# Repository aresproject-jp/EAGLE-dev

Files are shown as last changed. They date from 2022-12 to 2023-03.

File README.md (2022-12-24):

# EAGLE-dev
## projects
ARES3号機向けの回路の共同開発用ワークスペースです。
EAGLEのschファイルとbrdファイルを同じ名前のフォルダ内に保存して管理して下さい。
EAGLEの推奨バージョンは9.6.2です。
## libraries
各モジュールのライブラリを共有します。/computers /sensors /element /motor /connectorの5つの
フォルダを用意しています。以下の基準に従って分類して下さい。
- computers : コンピュータ及びマイクロコンピュータ　ex)jetson nano, raspberypi, arduino
- sensors   : 各センサモジュール　ex)BNO055, BMP180
- element   : 回路素子　ex)PchMosfet, DCDCconverter
- motor     : モーター関連のモジュール　ex)モータードライバ, エンコーダ
- connector : コネクタ類
## 3Dmodels
EAGLEにデフォルトで3Dデータが登録されていない部品の3Dデータ(*step)をアップロードしてください。
分類方法はlibrariesと同様です。
## documets
参考資料およびシステム図

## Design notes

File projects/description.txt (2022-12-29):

any comment is OK

power_supply => @kato shunsuke
jetson => @saizaki tomoki
arduino => @higuchi fuka

controll unit{
    module:jetson, BNO055, BMP180, CAN(MCP2562), GPS, 2.4GHz wireless communication module
    powersupply:5V from PU
    fan
    camera
    interface:terminalblock => 5V,GND CANH,CAL * 2

    eagle library:jetson, GPS, wirelessPin(5V,3V3, GND, RX, TX) 15min * 3 = 45min
    schematic 60min
    bord 30min
    3D ×
    deadline 1/3

    progress:
}

motor unit{
    module:ArduinoMega, motordriver(screw hole + terminalblock),CAN, encoder(4lines)
    powersupply:5V,18V from PU
    interface:terminalblock => 5V,GND,18V,CANH,CANL * 2
              connector => 4*4
    eagle library:motordriver,MCP2515r,ArduinoMega
}

power unit{
    eagle library:pulse generator
}

asks{
    systems, write down questions => kato
    e-mail => zaki
    deadline 1/3
}

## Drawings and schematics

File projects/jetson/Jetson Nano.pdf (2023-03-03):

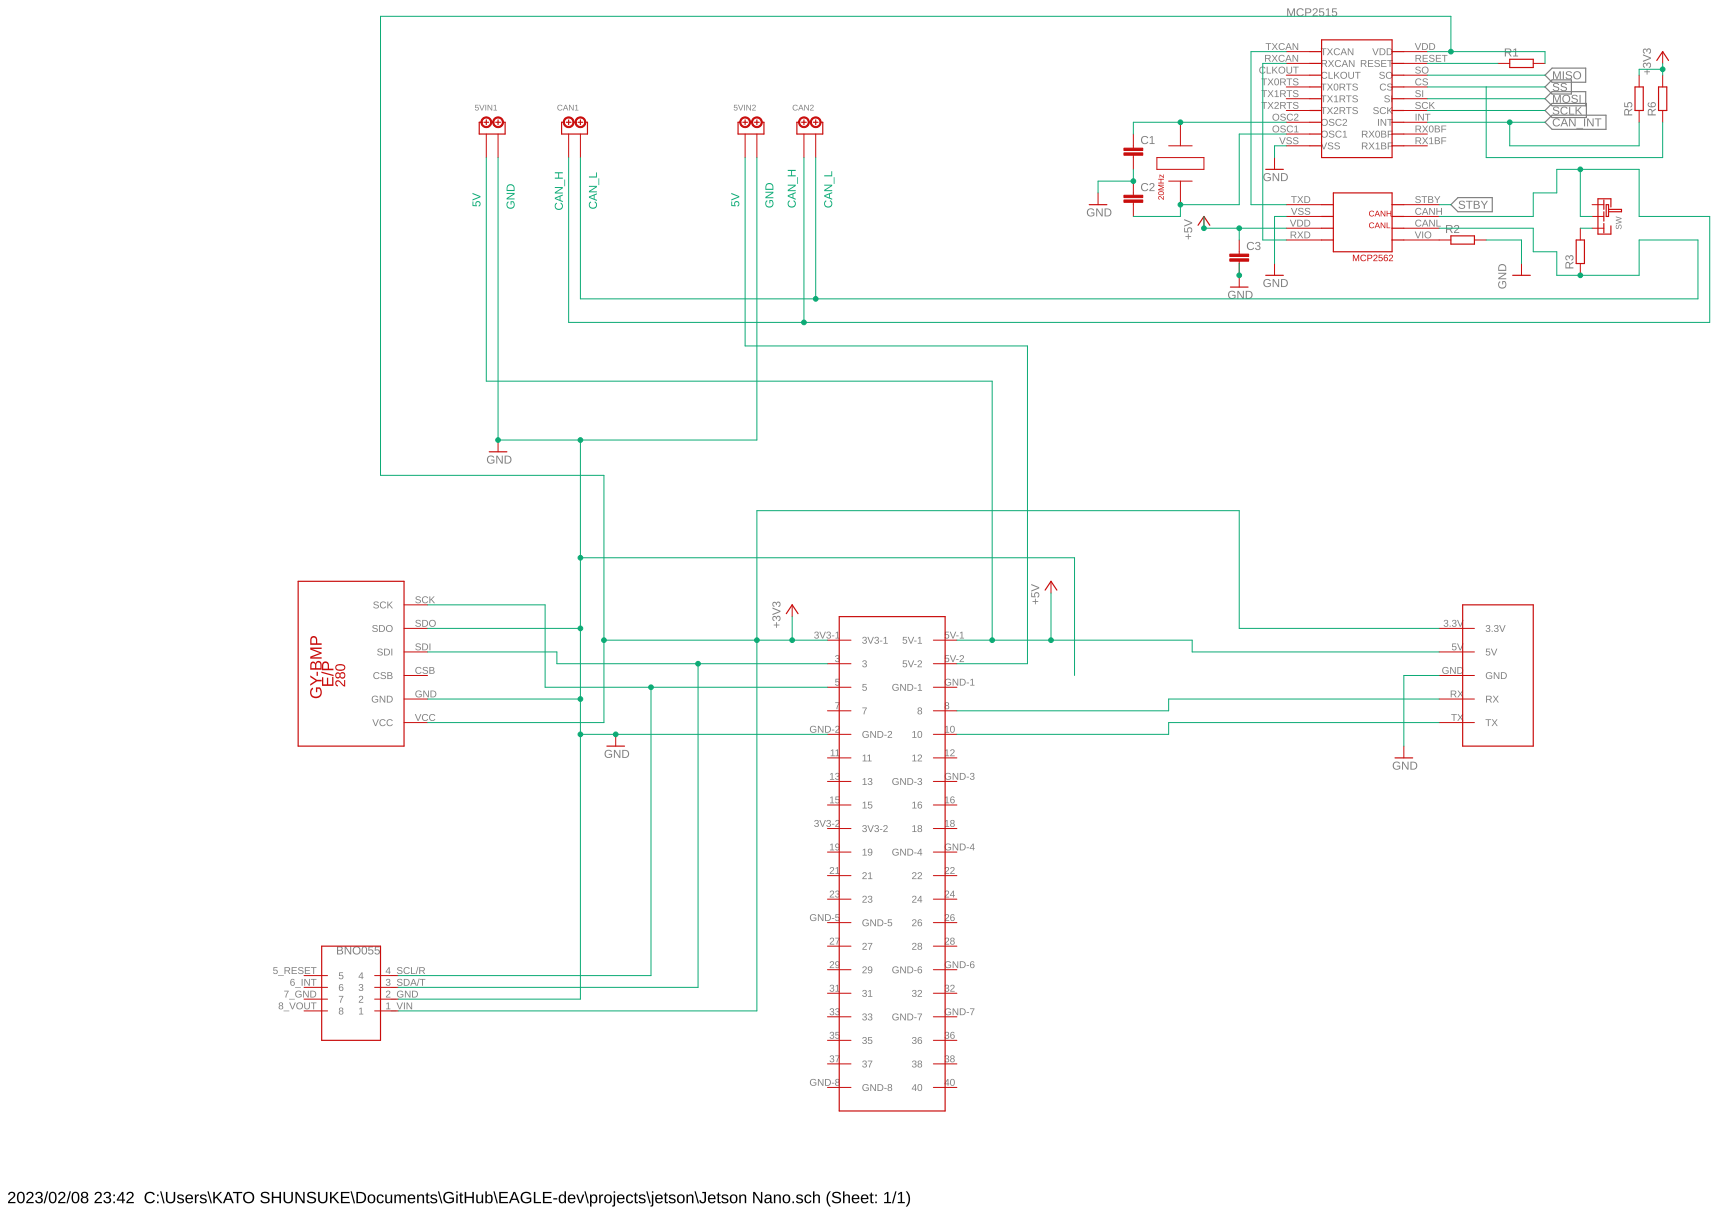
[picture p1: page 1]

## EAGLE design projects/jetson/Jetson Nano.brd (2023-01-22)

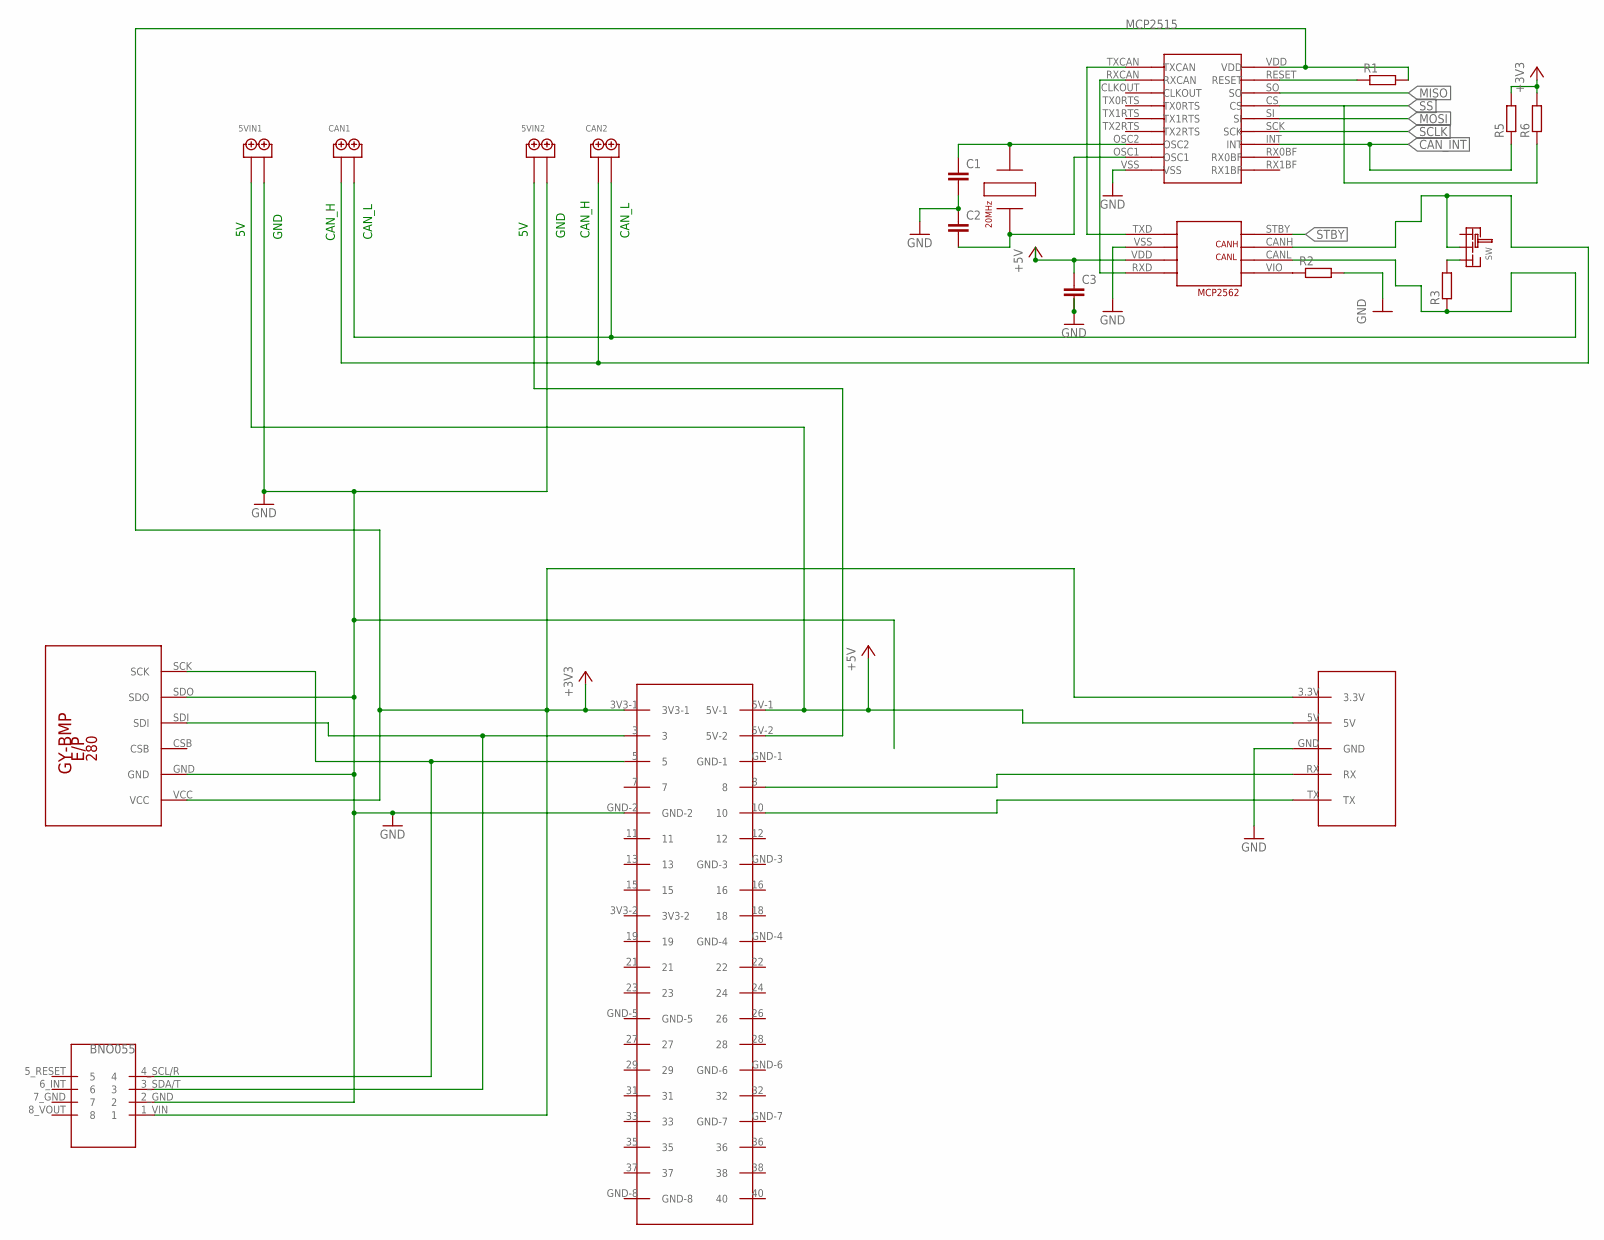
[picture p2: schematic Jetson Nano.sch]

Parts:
5VIN1, 5VIN2: 2PIN
C1, C2, C3: C-EU025-024X044; C025-024X044
CAN1, CAN2: 2PIN
JN1: JETSON_NANO
MCP1: MCP2515
R1, R2, R3, R5, R6: R-EU_0207/10; 0207/10
SW: SRIDE_SWITCH
U$1: GY-BPM280; GY-BMP280-FOOTPRINT
U$2: BNO055
U$3: WIRELESS_PINS
U$4: MCP2562
U$5: HUSG20

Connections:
5V_2: 5VIN2.P$1, JN1.5V-2
+3V3: JN1.3V3-1, MCP1.VDD, R1.2, R5.2, R6.2, U$1.VCC, U$2.1_VIN (1), U$3.3.3V
+5V_1: 5VIN1.P$1, C3.1, JN1.5V-1, U$3.5V, U$4.VDD
CAN_H2: CAN1.P$1, CAN2.P$1, SW.LR, U$4.CANH
CAN_INT: MCP1.INT, R5.1
GND: 5VIN1.P$2, 5VIN2.P$2, C1.2, C2.1, C3.2, JN1.GND-2, MCP1.VSS, U$1.GND, U$1.SDO, U$2.2_GND (2), U$3.GND, U$4.VSS
MISO: MCP1.SO
MOSI: MCP1.SI
unnamed: JN1.3, U$1.SDI, U$2.3_SDA/T (3)
unnamed: JN1.5, U$1.SCK, U$2.4_SCL/R (4)
unnamed: C1.1, MCP1.OSC2, U$5.A
unnamed: C2.2, MCP1.OSC1, U$5.B
unnamed: MCP1.TXCAN, U$4.TXD
unnamed: MCP1.RXCAN, U$4.RXD
unnamed: JN1.8, U$3.RX
unnamed: JN1.10, U$3.TX
unnamed: MCP1.RESET, R1.1
unnamed: R2.1, U$4.VIO
unnamed: R3.2, SW.R
unnamed: CAN1.P$2, CAN2.P$2, R3.1, U$4.CANL
SCLK: MCP1.SCK
SS: MCP1.CS, R6.1
STBY: U$4.STBY

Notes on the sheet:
GND
CAN_H
CAN_L

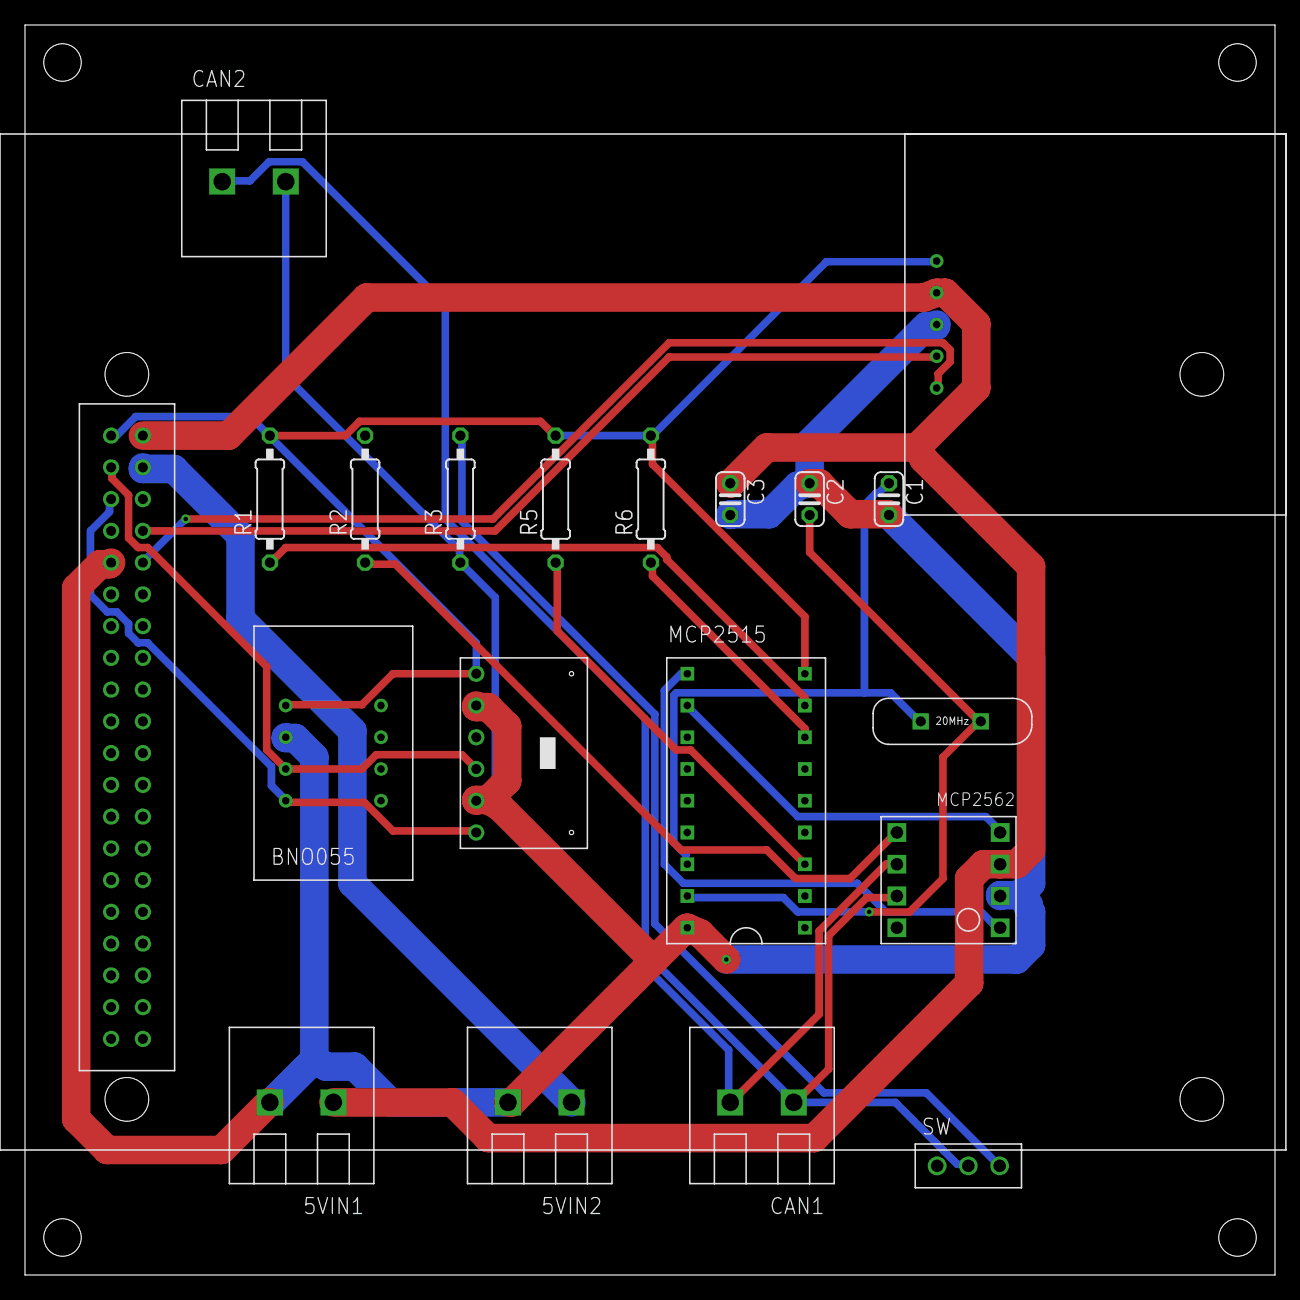
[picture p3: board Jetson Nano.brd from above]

Board: 2 copper layers, 100.0 x 100.0 mm, 20 parts (0 on the bottom side), 19 nets.

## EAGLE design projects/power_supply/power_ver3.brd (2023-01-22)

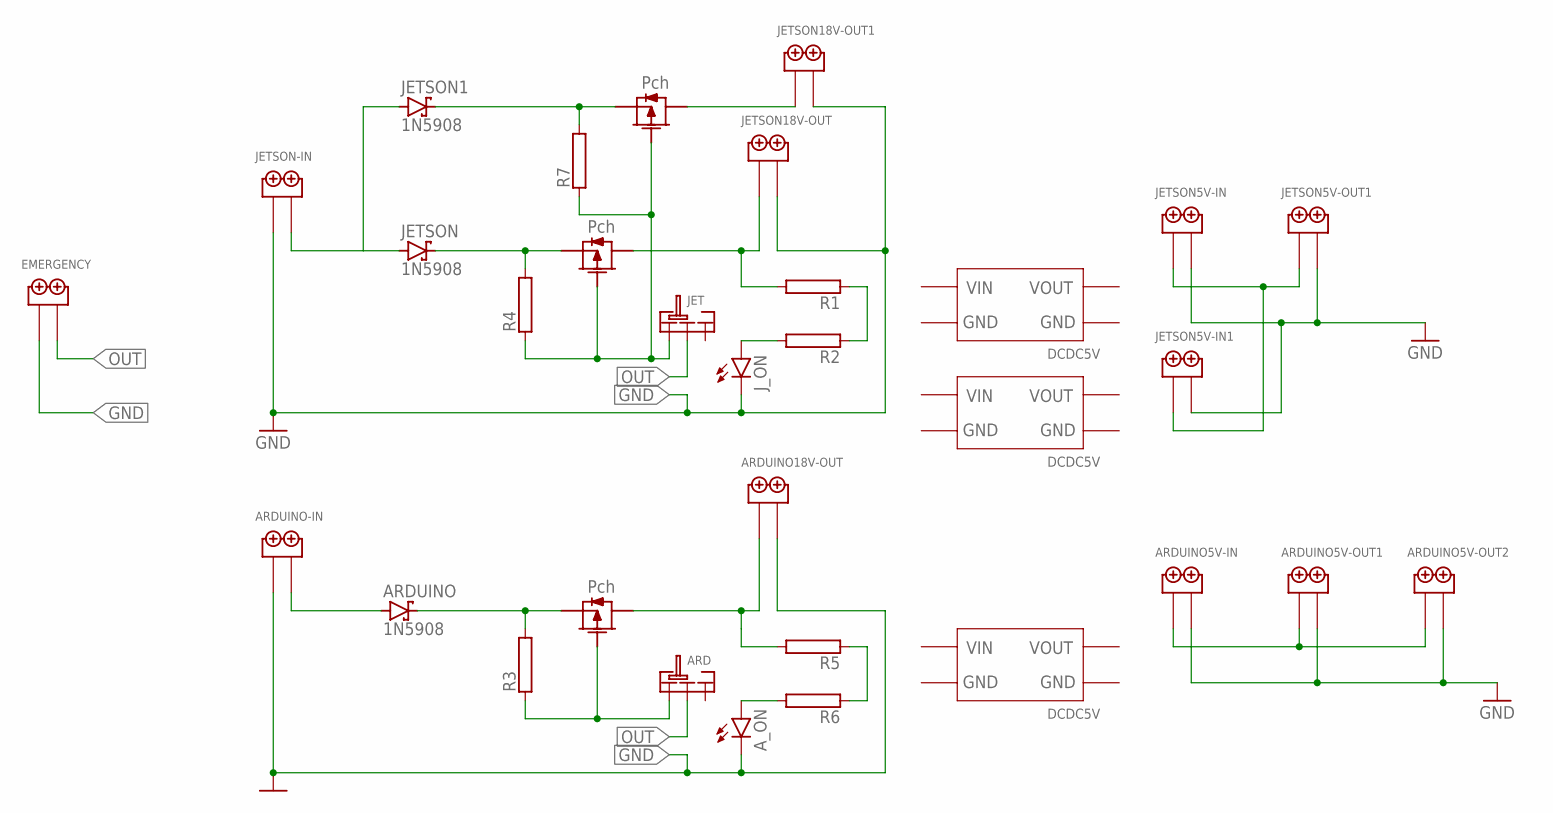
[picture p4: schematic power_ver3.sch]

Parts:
ARD: SRIDE_SWITCH
ARDUINO: 1N5908; C4111-15
ARDUINO5V-IN, ARDUINO5V-OUT1, ARDUINO5V-OUT2, ARDUINO18V-OUT: 2PIN
ARDUINO-IN: 2PIN
A_ON: LED5MM
EMERGENCY: 2PIN
JET: SRIDE_SWITCH
JETSON, JETSON1: 1N5908; C4111-15
JETSON5V-IN, JETSON5V-IN1, JETSON5V-OUT1, JETSON18V-OUT, JETSON18V-OUT1: 2PIN
JETSON-IN: 2PIN
J_ON: LED5MM
R1, R2, R3, R4, R5, R6, R7: RAC01; AC01
U$1, U$4, U$5: 2SJ334
U$2, U$6, U$23: DCDCDEV

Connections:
18V: JETSON.A, JETSON1.A, JETSON-IN.P$2
GND: ARDUINO5V-IN.P$2, ARDUINO5V-OUT1.P$2, ARDUINO5V-OUT2.P$2, ARDUINO18V-OUT.P$2, ARDUINO-IN.P$1, A_ON.K (C), EMERGENCY.P$1, JETSON5V-IN.P$2, JETSON5V-IN1.P$2, JETSON5V-OUT1.P$2, JETSON18V-OUT.P$2, JETSON18V-OUT1.P$2, JETSON-IN.P$1, J_ON.K (C)
MA: JETSON.C, R4.2, U$4.SOURCE
MA1: JETSON1.C, R7.2, U$1.SOURCE
MAC: JETSON18V-OUT.P$1, R1.2, U$4.DRAIN
MAD: JETSON5V-IN.P$1, JETSON5V-IN1.P$1, JETSON5V-OUT1.P$1
MBB: ARDUINO.A, ARDUINO-IN.P$2
MKK: ARDUINO.C, R3.2, U$5.SOURCE
ML: ARDUINO5V-IN.P$1, ARDUINO5V-OUT1.P$1, ARDUINO5V-OUT2.P$1
MOO: ARDUINO18V-OUT.P$1, R5.2, U$5.DRAIN
unnamed: ARD.L, R3.1, U$5.GATE
unnamed: J_ON.A, R2.2
unnamed: A_ON.A, R6.2
unnamed: JET.L, R4.1, R7.1, U$1.GATE, U$4.GATE
unnamed: JETSON18V-OUT1.P$1, U$1.DRAIN
unnamed: R5.1, R6.1
unnamed: R1.1, R2.1
OUT: ARD.LR, EMERGENCY.P$2, JET.LR

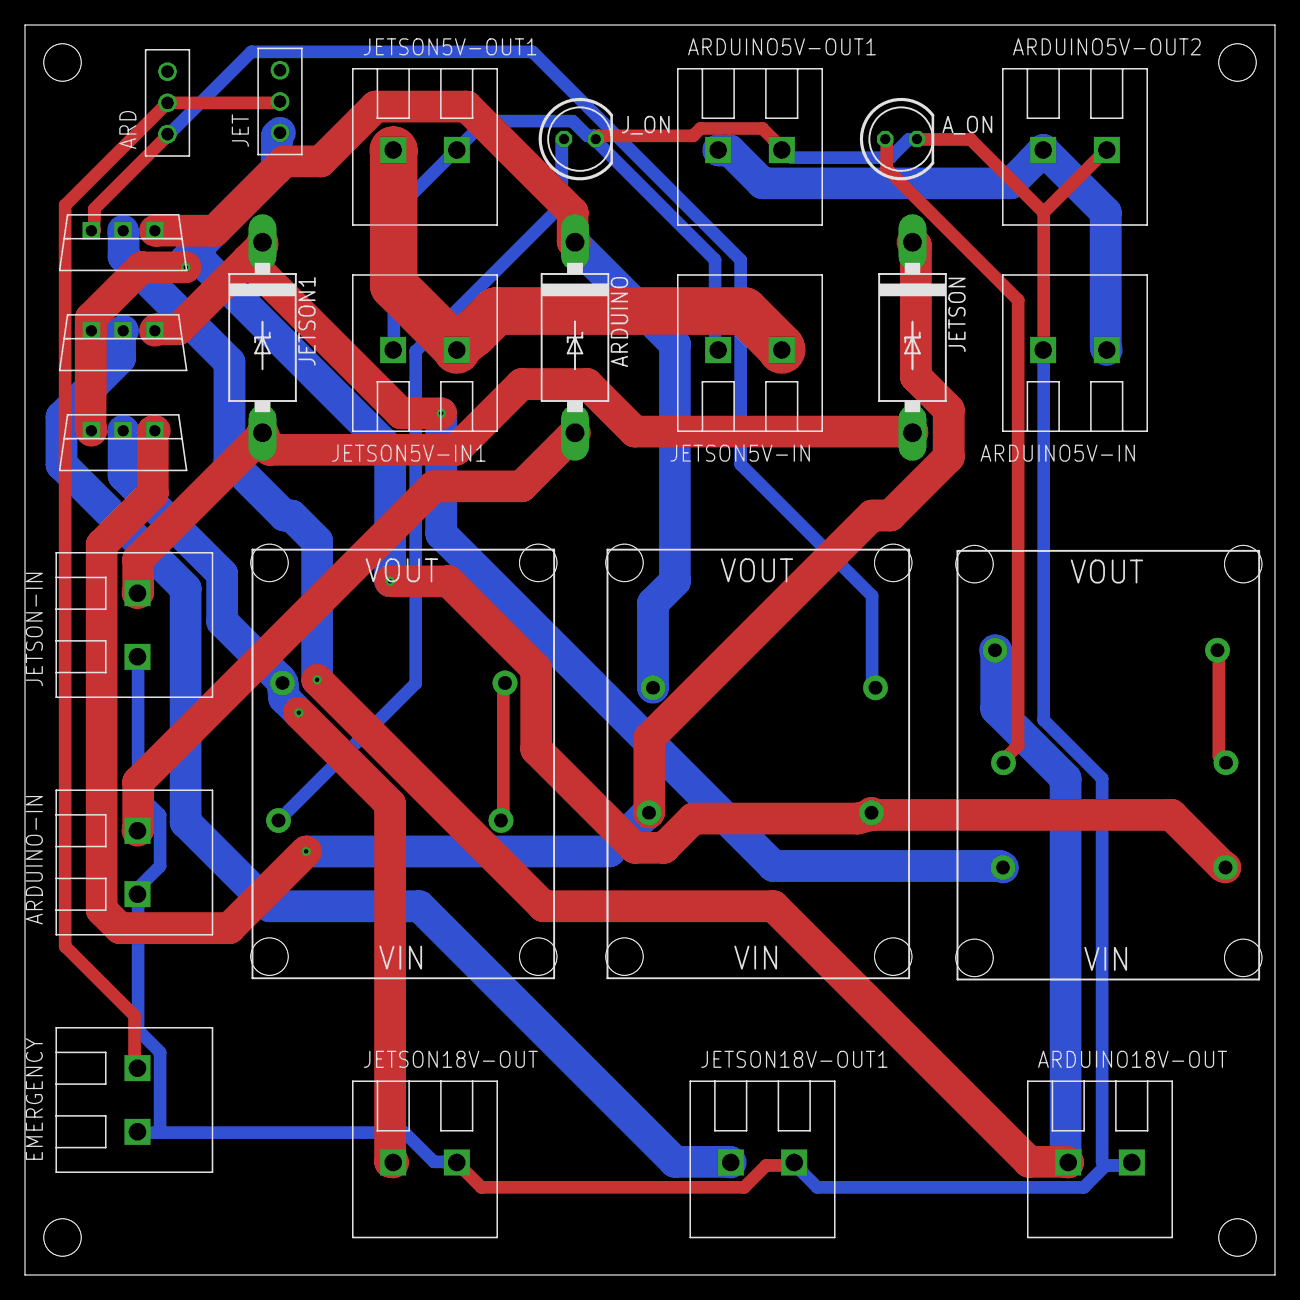
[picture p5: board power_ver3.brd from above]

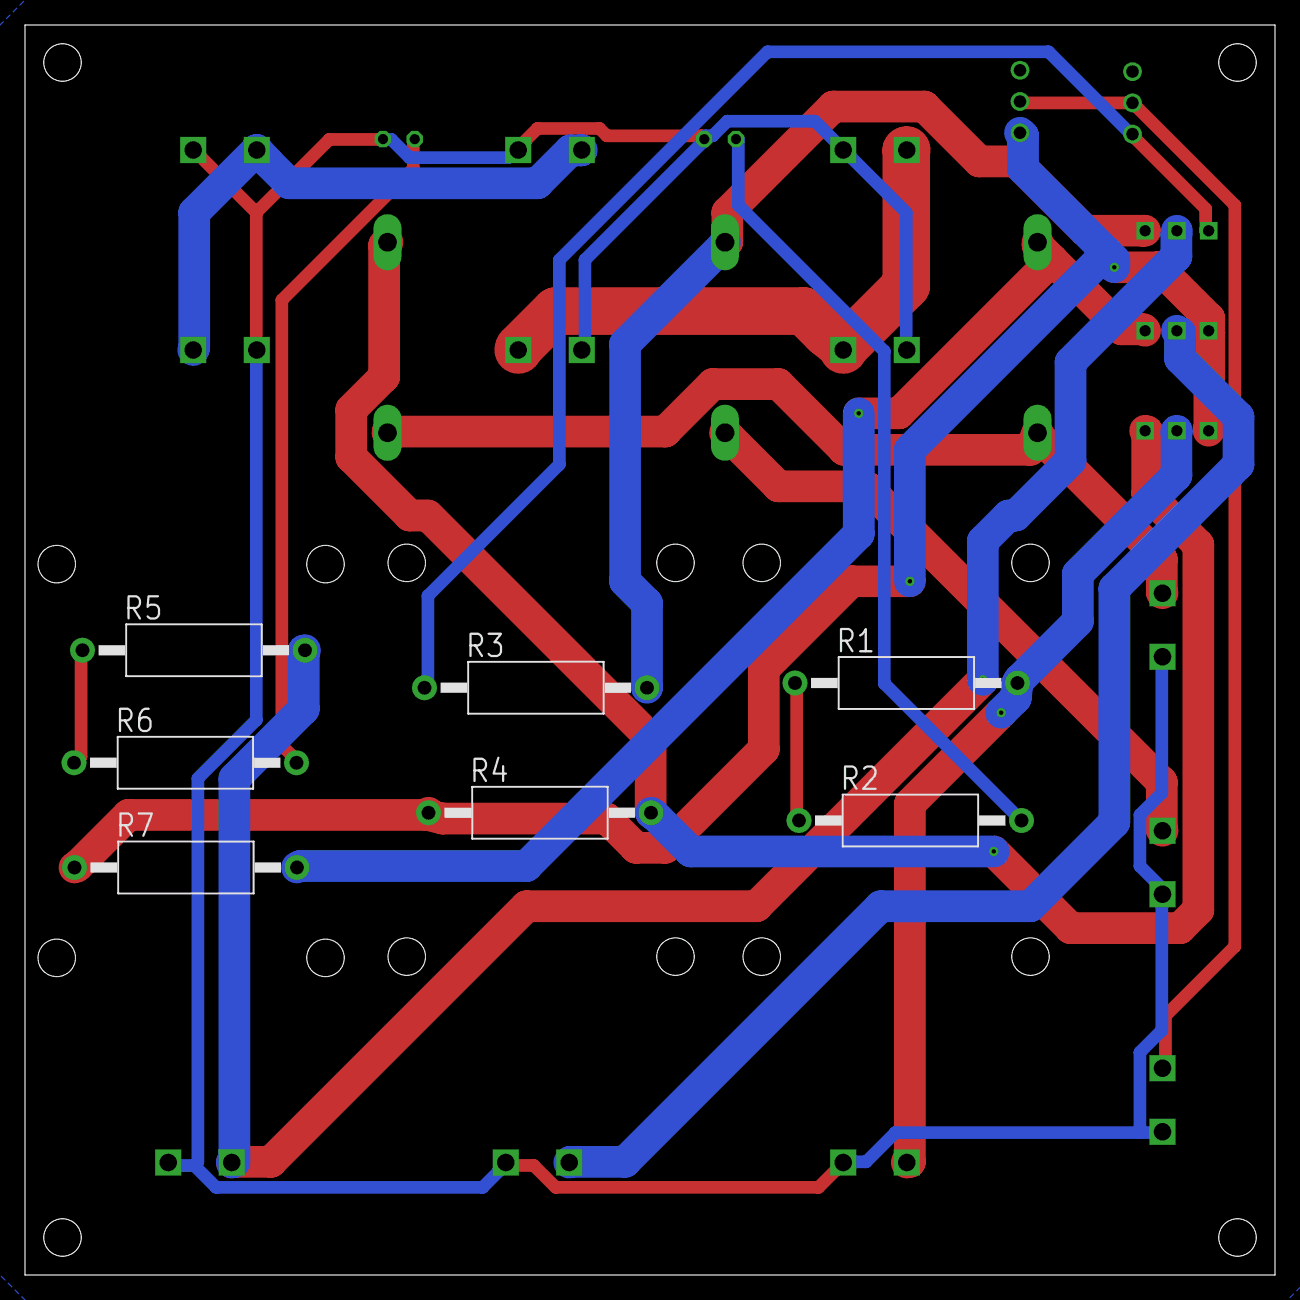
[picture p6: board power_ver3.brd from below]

Board: 2 copper layers, 100.0 x 100.0 mm, 32 parts (7 on the bottom side), 18 nets.

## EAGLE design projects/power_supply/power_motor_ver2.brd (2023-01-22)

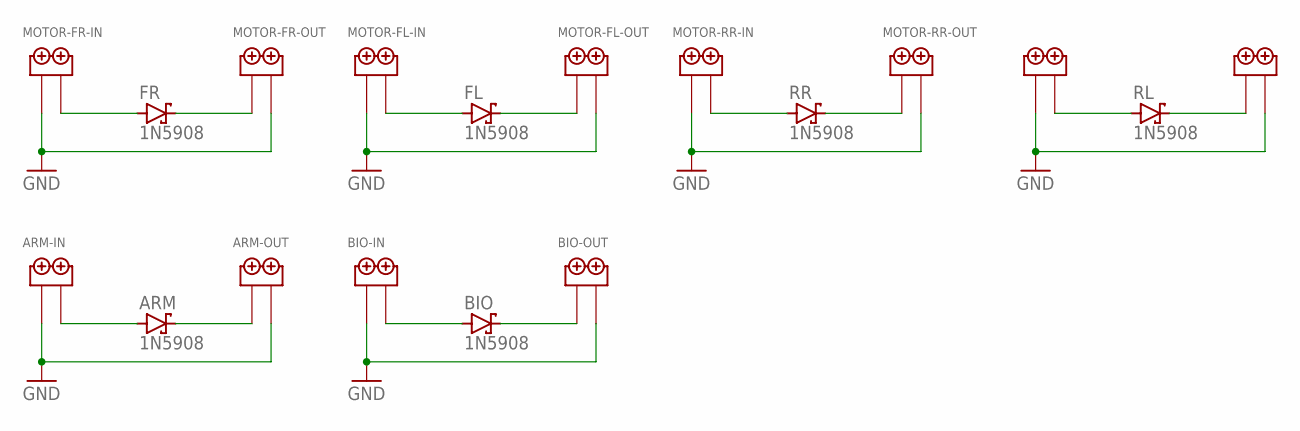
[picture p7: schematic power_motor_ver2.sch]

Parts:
ARM: 1N5908; C4111-15
ARM-IN: 2PIN
ARM-OUT: 2PIN
BIO: 1N5908; C4111-15
BIO-IN: 2PIN
BIO-OUT: 2PIN
FL: 1N5908; C4111-15
FR: 1N5908; C4111-15
MOTOR-FL-IN: 2PIN
MOTOR-FL-OUT: 2PIN
MOTOR-FR-IN: 2PIN
MOTOR-FR-OUT: 2PIN
MOTOR-RL-IN: 2PIN
MOTOR-RL-OUT: 2PIN
MOTOR-RR-IN: 2PIN
MOTOR-RR-OUT: 2PIN
RL: 1N5908; C4111-15
RR: 1N5908; C4111-15

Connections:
GND: ARM-IN.P$1, ARM-OUT.P$2, BIO-IN.P$1, BIO-OUT.P$2, MOTOR-FL-IN.P$1, MOTOR-FL-OUT.P$2, MOTOR-FR-IN.P$1, MOTOR-FR-OUT.P$2, MOTOR-RL-IN.P$1, MOTOR-RL-OUT.P$2, MOTOR-RR-IN.P$1, MOTOR-RR-OUT.P$2
unnamed: FR.A, MOTOR-FR-IN.P$2
unnamed: FR.C, MOTOR-FR-OUT.P$1
unnamed: FL.A, MOTOR-FL-IN.P$2
unnamed: FL.C, MOTOR-FL-OUT.P$1
unnamed: MOTOR-RR-IN.P$2, RR.A
unnamed: MOTOR-RR-OUT.P$1, RR.C
unnamed: MOTOR-RL-IN.P$2, RL.A
unnamed: MOTOR-RL-OUT.P$1, RL.C
unnamed: ARM.A, ARM-IN.P$2
unnamed: ARM.C, ARM-OUT.P$1
unnamed: BIO.A, BIO-IN.P$2
unnamed: BIO.C, BIO-OUT.P$1

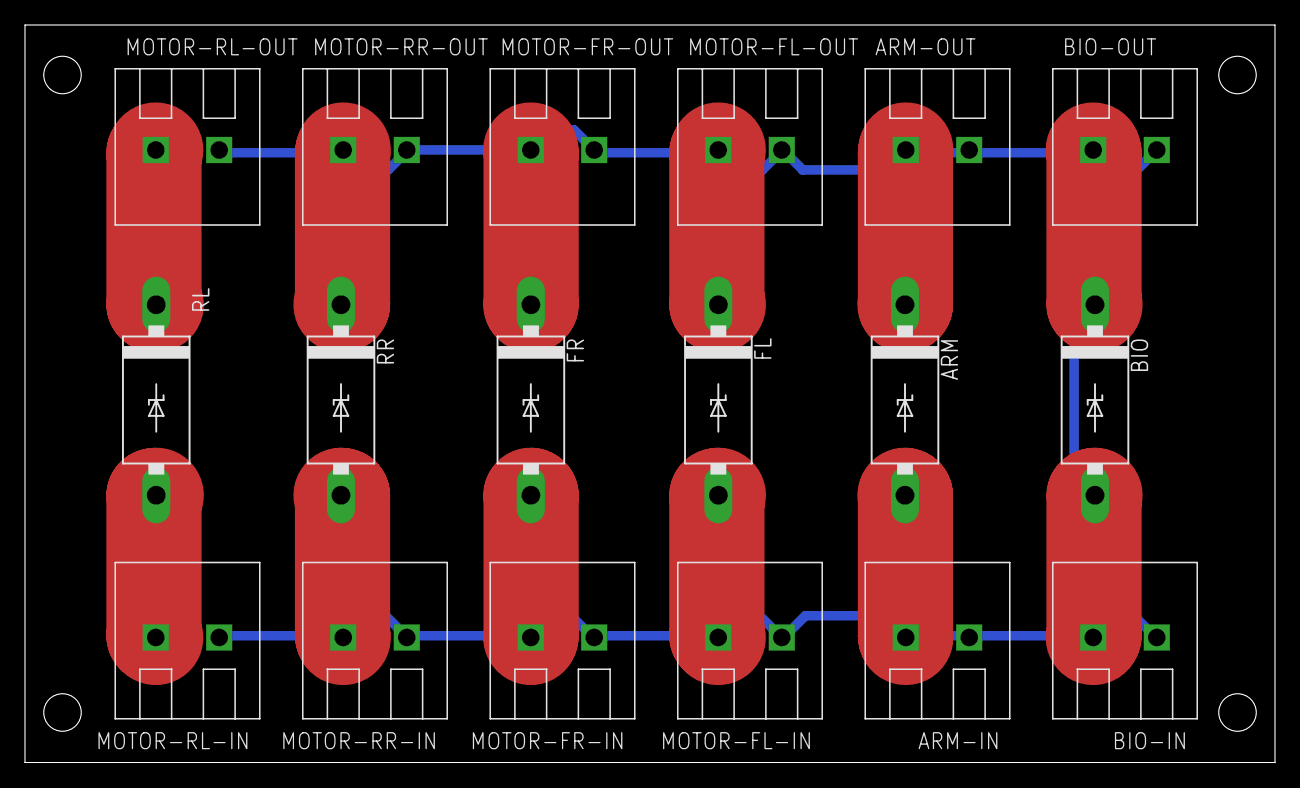
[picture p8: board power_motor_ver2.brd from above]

Board: 2 copper layers, 100.0 x 59.0 mm, 18 parts (0 on the bottom side), 13 nets.

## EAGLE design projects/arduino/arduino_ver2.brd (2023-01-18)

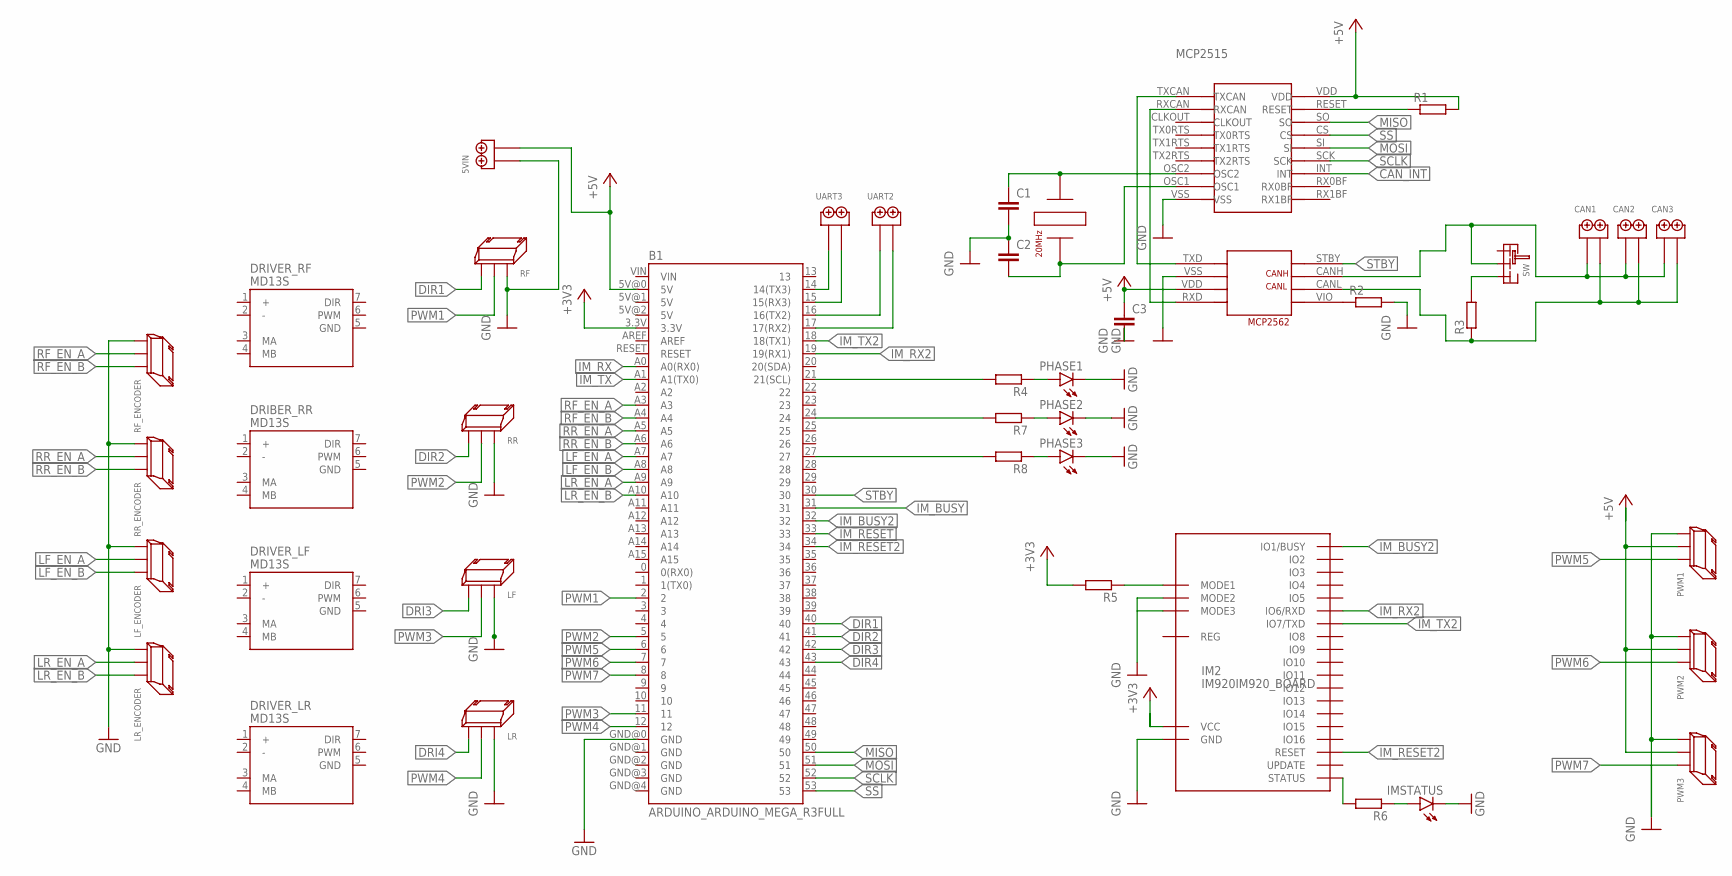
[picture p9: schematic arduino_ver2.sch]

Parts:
5VIN: 2PIN
B1: ARDUINO_ARDUINO_MEGA_R3FULL; ARDUINO_ARDUINO_MEGA
C1, C2, C3: C-EU025-024X044; C025-024X044
CAN1, CAN2, CAN3: 2PIN
DRIBER_RR: MD13S
DRIVER_LF: MD13S
DRIVER_LR: MD13S
DRIVER_RF: MD13S
IM2: IM920IM920_BOARD; IM920_BOARD
IMSTATUS: LED3MM
LF: 3PIN_SIDE
LF_ENCODER: 3PIN_SIDE
LR: 3PIN_SIDE
LR_ENCODER: 3PIN_SIDE
MCP2: MCP2515
PHASE1, PHASE2, PHASE3: LED3MM
PWM1, PWM2, PWM3: 3PIN_SIDE
R1, R2, R3, R4, R5, R6, R7, R8: R-EU_0207/10; 0207/10
RF: 3PIN_SIDE
RF_ENCODER: 3PIN_SIDE
RR: 3PIN_SIDE
RR_ENCODER: 3PIN_SIDE
SW: SRIDE_SWITCH
U$1: MCP2562
U$3: HUSG20
UART2, UART3: 2PIN

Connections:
+3V3: B1.3.3V, R5.2
+5V: 5VIN.P$2, B1.5V@0 (5V), C3.1, MCP2.VDD, R1.2, U$1.VDD
CAN_INT: MCP2.INT
DIR1: B1.40, RF.P$2
DIR2: B1.41, RR.P$2
DIR3: B1.42
DIR4: B1.43
DRI3: LF.P$2
DRI4: LR.P$2
GND: B1.GND@0 (GND), IMSTATUS.K (C), LF_ENCODER.P$2, LR_ENCODER.P$2, PHASE1.K (C), PHASE2.K (C), PHASE3.K (C), R2.2, RF_ENCODER.P$2, RR_ENCODER.P$2
IM_BUSY: B1.31
IM_BUSY2: B1.32, IM2.IO1 (IO1/BUSY)
IM_RESET: B1.33
IM_RESET2: B1.34, IM2.IO25 (RESET)
IM_RX: B1.A0 (A0(RX0))
IM_RX2: B1.19 (19(RX1)), IM2.IO6 (IO6/RXD)
IM_TX: B1.A1 (A1(TX0))
IM_TX2: B1.18 (18(TX1)), IM2.IO7 (IO7/TXD)
LF_EN_A: B1.A7, LF_ENCODER.P$1
LF_EN_B: B1.A8, LF_ENCODER.P$3
LR_EN_A: B1.A9, LR_ENCODER.P$1
LR_EN_B: B1.A10, LR_ENCODER.P$3
MISO: B1.50, MCP2.SO
MOSI: B1.51, MCP2.SI
unnamed: C1.1, MCP2.OSC2, U$3.A
unnamed: C2.2, MCP2.OSC1, U$3.B
unnamed: MCP2.TXCAN, U$1.TXD
unnamed: MCP2.RXCAN, U$1.RXD
unnamed: MCP2.RESET, R1.1
unnamed: R2.1, U$1.VIO
unnamed: CAN1.P$1, CAN2.P$1, CAN3.P$1, SW.LR, U$1.CANH
unnamed: R3.2, SW.R
unnamed: B1.21 (21(SCL)), R4.2
unnamed: CAN1.P$2, CAN2.P$2, CAN3.P$2, R3.1, U$1.CANL
unnamed: PHASE1.A, R4.1
unnamed: PWM1.P$2, PWM2.P$2, PWM3.P$2
unnamed: IM2.IO21 (STATUS), R6.2
unnamed: IMSTATUS.A, R6.1
unnamed: PWM1.P$1, PWM2.P$1, PWM3.P$1
unnamed: B1.24, R7.2
unnamed: PHASE2.A, R7.1
unnamed: B1.27, R8.2
unnamed: PHASE3.A, R8.1
unnamed: B1.14 (14(TX3)), UART3.P$1
unnamed: B1.15 (15(RX3)), UART3.P$2
unnamed: B1.16 (16(TX2)), UART2.P$1
unnamed: B1.17 (17(RX2)), UART2.P$2
unnamed: IM2.IO17 (MODE1), R5.1
PWM1: B1.2, RF.P$1
PWM2: B1.5, RR.P$1
PWM3: B1.11, LF.P$1
PWM4: B1.12, LR.P$1
PWM5: B1.6, PWM1.P$3
PWM6: B1.7, PWM2.P$3
PWM7: B1.8, PWM3.P$3
RF_EN_A: B1.A3, RF_ENCODER.P$1
RF_EN_B: B1.A4, RF_ENCODER.P$3
RR_EN_A: B1.A5, RR_ENCODER.P$1
RR_EN_B: B1.A6, RR_ENCODER.P$3
SCLK: B1.52, MCP2.SCK
SS: B1.53, MCP2.CS
STBY: B1.30, U$1.STBY
V-: 5VIN.P$1, C1.2, C2.1, C3.2, IM2.IO18 (MODE2), IM2.IO24 (GND), LF.P$3, LR.P$3, MCP2.VSS, RF.P$3, RR.P$3, U$1.VSS

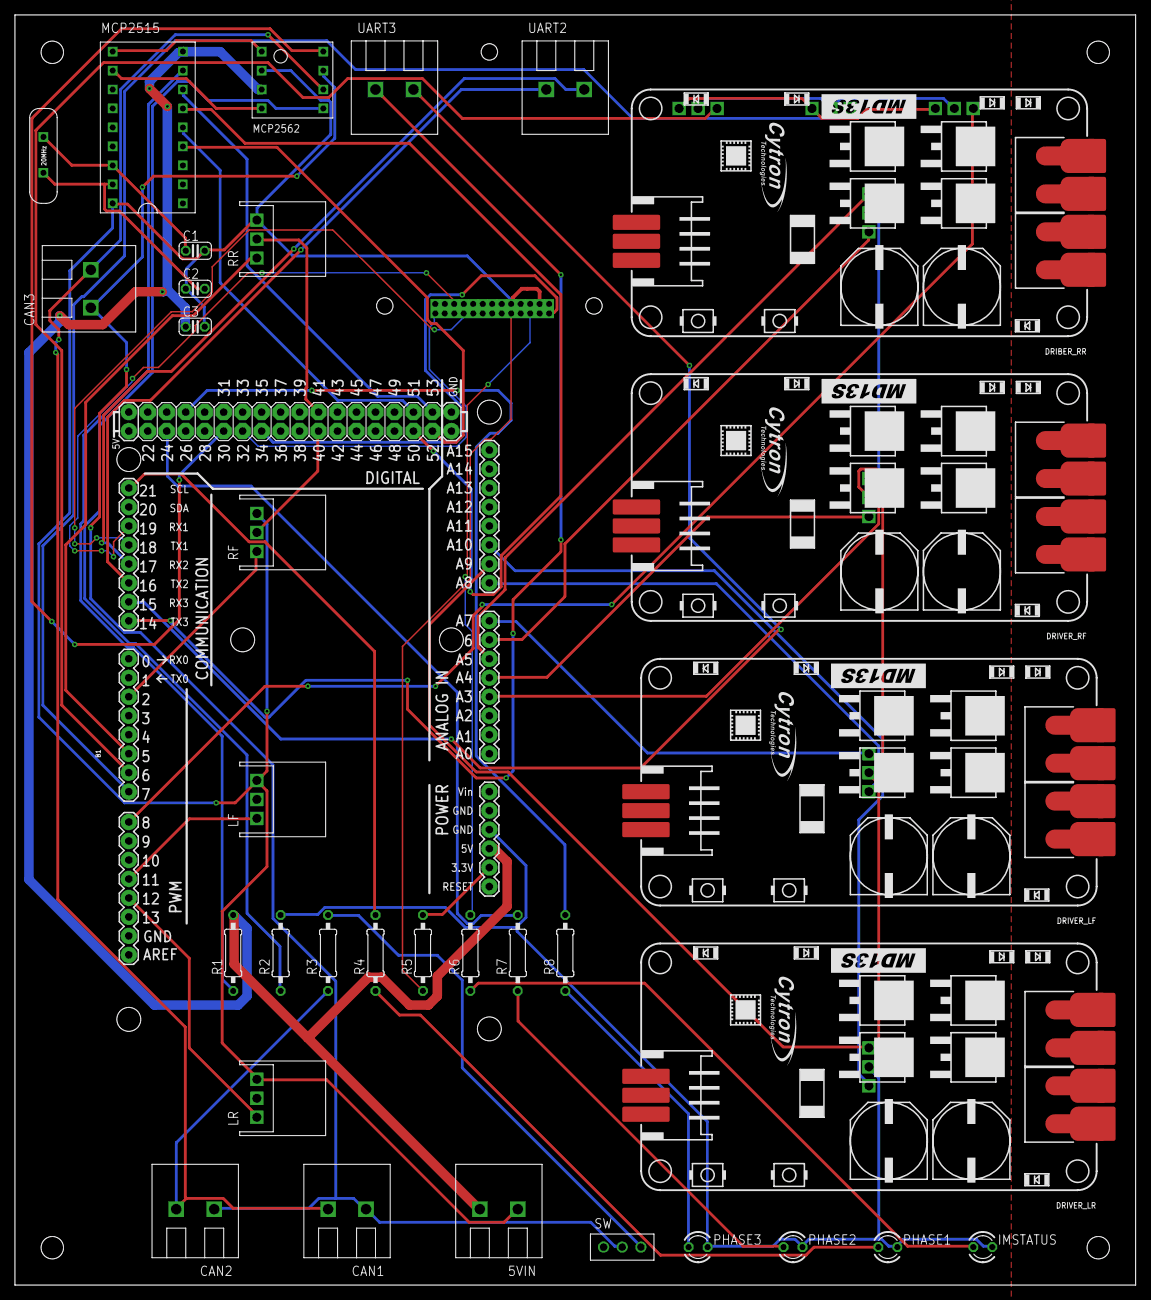
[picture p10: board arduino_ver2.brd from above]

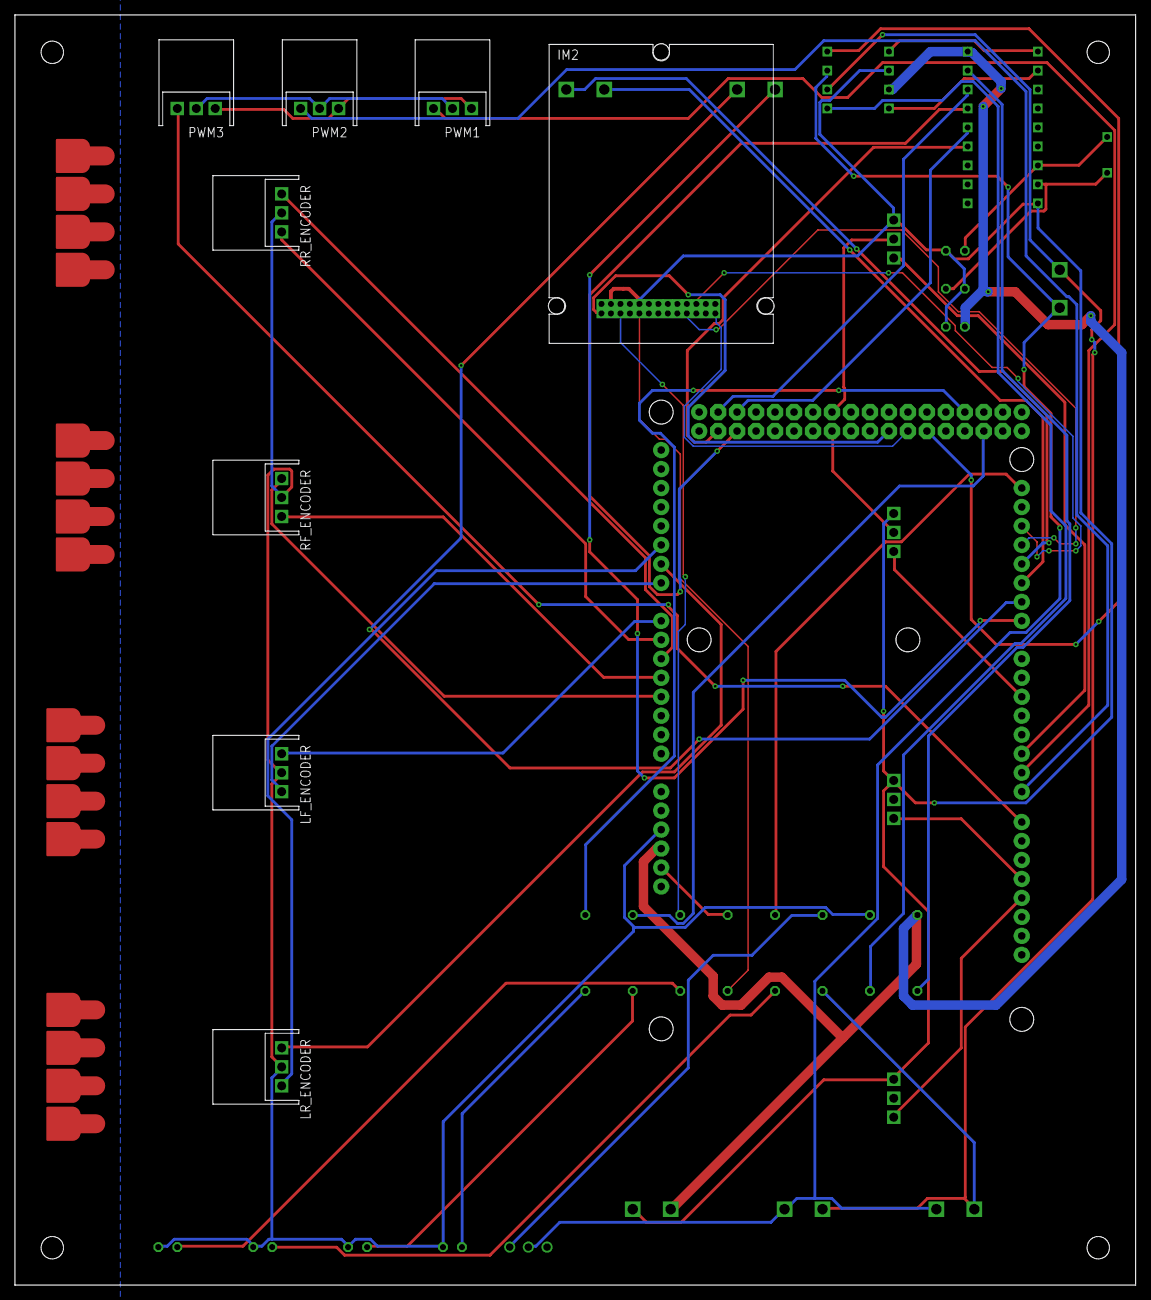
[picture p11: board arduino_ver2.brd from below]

Board: 2 copper layers, 150.0 x 170.0 mm, 42 parts (8 on the bottom side), 54 nets.

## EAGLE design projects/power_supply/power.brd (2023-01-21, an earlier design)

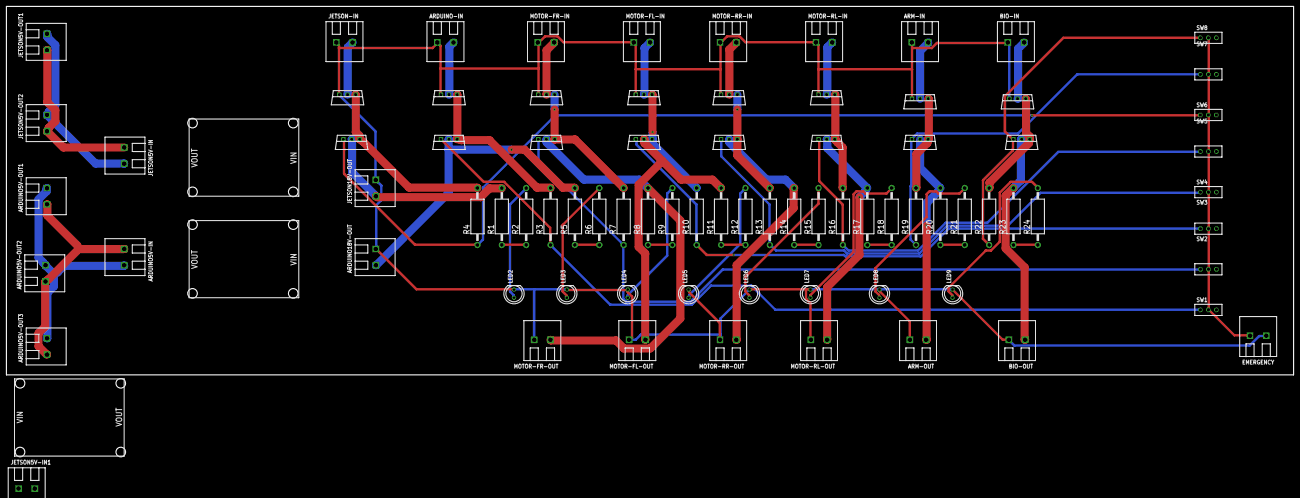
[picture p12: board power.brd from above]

Board: 2 copper layers, 402.6 x 115.2 mm, 84 parts (0 on the bottom side), 54 nets.

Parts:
ARDUINO5V-IN, ARDUINO5V-OUT1, ARDUINO5V-OUT2, ARDUINO5V-OUT3, ARDUINO18V-OUT: 2PIN
ARDUINO-IN: 2PIN
ARM-IN: 2PIN
ARM-OUT: 2PIN
BIO-IN: 2PIN
BIO-OUT: 2PIN
EMERGENCY: 2PIN
JETSON5V-IN, JETSON5V-IN1, JETSON5V-OUT1, JETSON5V-OUT2, JETSON18V-OUT: 2PIN
JETSON-IN: 2PIN
LED2, LED3, LED4, LED5, LED6, LED7, LED8, LED9: LED5MM
MOTOR-FL-IN: 2PIN
MOTOR-FL-OUT: 2PIN
MOTOR-FR-IN: 2PIN
MOTOR-FR-OUT: 2PIN
MOTOR-RL-IN: 2PIN
MOTOR-RL-OUT: 2PIN
MOTOR-RR-IN: 2PIN
MOTOR-RR-OUT: 2PIN
R1, R2, R3, R4, R5, R6, R7, R8, R9, R10, R11, R12, R13, R14, R15, R16, R17, R18, R19, R20, R21, R22, R23, R24: AC01
SW1, SW2, SW3, SW4, SW5, SW6, SW7, SW8: SRIDE_SWITCH
U$1, U$3, U$4, U$5, U$7, U$8, U$10, U$11, U$13, U$14, U$16, U$17, U$20, U$21, U$24, U$25: 2SJ334
U$2, U$6, U$23: DCDCDEV

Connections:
18V: JETSON-IN.P$2, U$3.DRAIN
IN: ARDUINO18V-OUT.P$2, ARDUINO-IN.P$1, ARM-IN.P$1, ARM-OUT.P$2, BIO-IN.P$1, BIO-OUT.P$2, EMERGENCY.P$1, JETSON18V-OUT.P$2, JETSON-IN.P$1, LED2.K, LED3.K, LED4.K, LED5.K, LED6.K, LED7.K, LED8.K, LED9.K, MOTOR-FL-IN.P$1, MOTOR-FL-OUT.P$2, MOTOR-FR-IN.P$1, MOTOR-FR-OUT.P$2, MOTOR-RL-IN.P$1, MOTOR-RL-OUT.P$2, MOTOR-RR-IN.P$1, MOTOR-RR-OUT.P$2, U$1.GATE, U$3.GATE, U$7.GATE, U$10.GATE, U$13.GATE, U$16.GATE, U$20.GATE, U$24.GATE
MA: R4.2, U$3.SOURCE, U$4.SOURCE
MAC: JETSON18V-OUT.P$1, R1.2, U$4.DRAIN
MAD: JETSON5V-IN.P$1, JETSON5V-IN1.P$2, JETSON5V-OUT1.P$1, JETSON5V-OUT2.P$1
MBB: ARDUINO-IN.P$2, U$1.DRAIN
MBV: R13.2, U$13.SOURCE, U$14.SOURCE
MCX: R16.2, U$16.SOURCE, U$17.SOURCE
MDSDS: BIO-IN.P$2, U$24.DRAIN
MGG: ARM-IN.P$2, U$20.DRAIN
MH: R10.2, U$10.SOURCE, U$11.SOURCE
MHGF: ARM-OUT.P$1, R20.2, U$21.DRAIN
MHH: MOTOR-RR-OUT.P$1, R14.2, U$14.DRAIN
MHHHH: BIO-OUT.P$1, R23.2, U$25.DRAIN
MJUY: R22.2, U$24.SOURCE, U$25.SOURCE
MKK: R3.2, U$1.SOURCE, U$5.SOURCE
ML: ARDUINO5V-IN.P$1, ARDUINO5V-OUT1.P$1, ARDUINO5V-OUT2.P$1, ARDUINO5V-OUT3.P$1
MN: MOTOR-RL-IN.P$2, U$16.DRAIN
MOO: ARDUINO18V-OUT.P$1, R5.2, U$5.DRAIN
MS: R7.2, U$7.SOURCE, U$8.SOURCE
MU: MOTOR-FR-IN.P$2, U$7.DRAIN
MV: MOTOR-FL-OUT.P$1, R11.2, U$11.DRAIN
MVVV: R19.2, U$20.SOURCE, U$21.SOURCE
MX: MOTOR-RR-IN.P$2, U$13.DRAIN
MY: MOTOR-FL-IN.P$2, U$10.DRAIN
MZZ: MOTOR-RL-OUT.P$1, R17.2, U$17.DRAIN
unnamed: R3.1, SW1.L, U$5.GATE
unnamed: LED2.A, R2.2
unnamed: LED3.A, R6.2
unnamed: LED4.A, R9.2
unnamed: R5.1, R6.1
unnamed: LED5.A, R12.2
unnamed: R22.1, SW8.L, U$25.GATE
unnamed: ARDUINO5V-IN.P$2, ARDUINO5V-OUT1.P$2, ARDUINO5V-OUT2.P$2, ARDUINO5V-OUT3.P$2
unnamed: R7.1, SW2.L, U$8.GATE
unnamed: LED6.A, R15.2
unnamed: LED7.A, R18.2
unnamed: MOTOR-FR-OUT.P$1, R8.2, U$8.DRAIN
unnamed: R8.1, R9.1
unnamed: LED8.A, R21.2
unnamed: LED9.A, R24.2
unnamed: JETSON5V-IN.P$2, JETSON5V-IN1.P$1, JETSON5V-OUT1.P$2, JETSON5V-OUT2.P$2
unnamed: R10.1, SW3.L, U$11.GATE
unnamed: R11.1, R12.1
unnamed: R13.1, SW4.L, U$14.GATE
unnamed: R14.1, R15.1
unnamed: R16.1, SW5.L, U$17.GATE
unnamed: R17.1, R18.1
unnamed: R4.1, SW6.L, U$4.GATE
unnamed: R1.1, R2.1
unnamed: R19.1, SW7.L, U$21.GATE
unnamed: R23.1, R24.1
unnamed: R20.1, R21.1
OUT: EMERGENCY.P$2, SW1.LR, SW2.LR, SW3.LR, SW4.LR, SW5.LR, SW6.LR, SW7.LR, SW8.LR

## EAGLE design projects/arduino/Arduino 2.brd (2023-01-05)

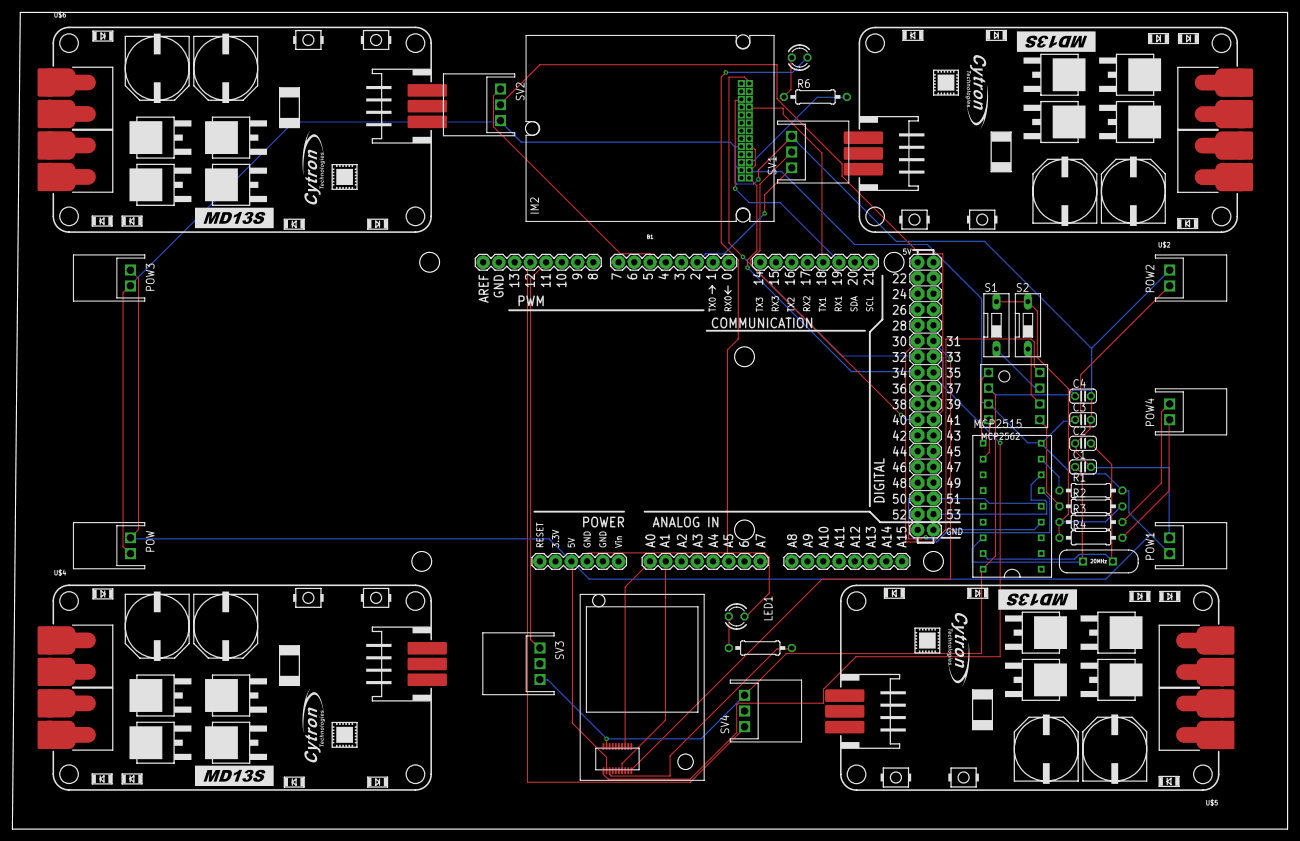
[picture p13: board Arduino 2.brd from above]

Board: 2 copper layers, 205.7 x 131.8 mm, 33 parts (0 on the bottom side), 37 nets.

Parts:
B1: ARDUINO_ARDUINO_MEGA_R3FULL; ARDUINO_ARDUINO_MEGA
C1, C2, C3, C4: C025-024X044
IM1: IM920C
IM2: IM920IM920_BOARD; IM920_BOARD
LED1, LED2: LED3MM
MCP1: MCP2515
POW, POW1, POW2, POW3, POW4: 2PIN_SIDE
R1, R2, R3, R4, R5, R6: 0207/10
S1, S2: DS-01
SV1, SV2, SV3, SV4: 3PIN_SIDE
U$1: MCP2562
U$2, U$4, U$5, U$6: MD13S
U$3: HUSG20

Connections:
+5V: B1.5V@0, C3.1, IM1.$P17, IM2.IO17, IM2.IO23, MCP1.VDD, POW.P$1, POW1.P$1, POW2.P$1, POW3.P$1, R1.2, U$1.VDD
DIR1: B1.40, SV1.P$2
DIR2: B1.41, SV2.P$2
GND: B1.GND@0, LED1.K, LED2.K
IM_BUSY: B1.31, IM1.$P1
IM_BUSY2: B1.32, IM2.IO1
IM_RESET: B1.33, IM1.$P19
IM_RESET2: B1.34, IM2.IO25
IM_RX: B1.A0, IM1.$P6
IM_RX2: B1.19, IM2.IO6
IM_TX: B1.A1, IM1.$P7
IM_TX2: B1.18, IM2.IO7
MISO: B1.50, MCP1.SO
MOSI: B1.51, MCP1.SI
unnamed: C1.1, MCP1.OSC2, U$3.A
unnamed: C2.2, MCP1.OSC1, U$3.B
unnamed: MCP1.TXCAN, U$1.TXD
unnamed: MCP1.RXCAN, U$1.RXD
unnamed: MCP1.RESET, R1.1
unnamed: R2.1, U$1.VIO
unnamed: POW4.P$2, R3.2
unnamed: S1.1, U$1.CANH
unnamed: S2.1, U$1.CANL
unnamed: C4.1, R2.2, R3.1, R4.1, S1.2, S2.2
unnamed: POW4.P$1, R4.2
unnamed: LED1.A, R5.1
unnamed: IM2.IO21, R6.2
unnamed: LED2.A, R6.1
unnamed: IM1.$P15, R5.2
PWM1: B1.2, SV1.P$1
PWM2: B1.5, SV2.P$1
PWM3: B1.11, SV3.P$1
PWM4: B1.12, SV4.P$1
SCLK: B1.52, MCP1.SCK
SS: B1.53, MCP1.CS
STBY: B1.30, U$1.STBY
V-: C1.2, C2.1, C3.2, C4.2, IM1.$P18, IM2.IO18, IM2.IO24, MCP1.VSS, POW.P$2, POW1.P$2, POW2.P$2, POW3.P$2, SV1.P$3, SV2.P$3, SV3.P$3, SV4.P$3, U$1.VSS

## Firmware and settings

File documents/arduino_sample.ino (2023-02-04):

#include <SPI.h>                  // ライブラリのインクルード
#include <nRF24L01.h>
#include <RF24.h>
#include <Servo.h>

Servo myservo;

RF24 radio(45, 44);                 // CE,CSNピンの指定
const byte address[6] = "00001";  // データを受信するアドレス
//int SERVO_PIN = 3;
int Y_pos;
int Angle;

const int h_duty = 600;
const int l_duty = 400;

const int DIR_RF = A2;
const int PWM_RF = 4;
const int DIR_RB = A4;
const int PWM_RB = 3;
const int DIR_LF = 7;
const int PWM_LF = 6;
const int DIR_LB = A6;
const int PWM_LB = 2;

void setup() {

  Serial.begin(9600);
  //myservo.attach (SERVO_PIN);
  
  pinMode(DIR_RB, OUTPUT);
  pinMode(PWM_RB, OUTPUT);

  pinMode(DIR_RF, OUTPUT);
  pinMode(PWM_RF, OUTPUT);

  pinMode(DIR_LB, OUTPUT);
  pinMode(PWM_LB, OUTPUT);

  pinMode(DIR_LF, OUTPUT);
  pinMode(PWM_LF, OUTPUT);

  


  radio.begin();                      // 無線オブジェクトの初期化
  radio.openReadingPipe(0, address);  // データ受信アドレスを指定
  radio.setPALevel(RF24_PA_MIN);      // 出力を最小に
  radio.startListening();             // 受信側として設定

  radio.setAutoAck(false);
  radio.setDataRate(RF24_250KBPS);


}

void RB_forward(int duty){
  digitalWrite(DIR_RB, LOW);
  analogWrite(PWM_RB, duty);
}

void RB_back(int duty){
  digitalWrite(DIR_RB, HIGH);
  analogWrite(PWM_RB, duty);
}

void RF_forward(int duty){
  digitalWrite(DIR_RF, LOW);
  analogWrite(PWM_RF, duty);
}

void RF_back(int duty){
  digitalWrite(DIR_RF, HIGH);
  analogWrite(PWM_RF, duty);
}

void LB_forward(int duty){
  digitalWrite(DIR_LB, HIGH);
  analogWrite(PWM_LB, duty);
}

void LB_back(int duty){
  digitalWrite(DIR_LB, LOW);
  analogWrite(PWM_LB, duty);
}

void LF_forward(int duty){
  digitalWrite(DIR_LF, HIGH);
  analogWrite(PWM_LF, duty);
}

void LF_back(int duty){
  digitalWrite(DIR_LF, LOW);
  analogWrite(PWM_LF, duty);
}


void loop() {

  int phase = 0;
  
  if (radio.available()) {
    radio.read(&phase, sizeof(phase));    // アナログ値を受信する
  }else{
    phase = 0;
  }

  analogWrite(2, 0);

  if (phase == 1 || phase == 0) {

    RF_forward(0);
    RB_forward(0);
    LF_forward(0);
    LB_forward(0);

    delay(100);
    
  }else if (phase == 2){

    RF_forward(h_duty);
    RB_forward(h_duty);
    LF_forward(h_duty);
    LB_forward(h_duty);

    delay(100);
    
  }else if (phase == 3){

    RF_forward(h_duty);
    RB_forward(h_duty);
    LF_forward(l_duty);
    LB_forward(h_duty);

    delay(100);
    
  }else if (phase == 4){

    RF_forward(l_duty);
    RB_forward(h_duty);
    LF_forward(h_duty);
    LB_forward(h_duty);

    delay(100);
    
  }else if (phase == 5){

    RF_back(h_duty);
    RB_back(h_duty);
    LF_back(h_duty);
    LB_back(h_duty);

    delay(100);
  }

}

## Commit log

2023-01-03 add lib
    [power.sch]
2023-01-03 update power
    [power.brd]
2023-01-05 create arduino
    [Arduino 2.brd, Arduino 2.sch]
2023-01-09 Create Control Unit sch, brd (not finished yet)
    [Control_Unit.brd, Control_Unit.sch]
2023-01-10 update cad
    [Arduino 2.sch, arduino.brd, arduino.sch]
2023-01-10 Create Jetson board
    [Jetson Nano.brd, Jetson Nano.sch]
2023-01-11 modify jetson nano and Arduino board
    [Control_Unit.brd, Control_Unit.sch, arduino.brd]
2023-01-11 create jetson without CAN
    [Jetson Nano without CAN.brd, Jetson Nano without CAN.sch, Jetson Nano.sch]
2023-01-12 change all
    [Jetson Nano.brd, Jetson Nano.sch, arduino_ver1.0.brd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]
2023-01-20 Place hole in Jetson board
    [Jetson Nano.brd]
2023-01-20 Autoroute Jetson Board
    [Jetson Nano.brd, Jetson Nano.sch]
2023-01-22 Resize Jetson Board
    [Jetson Nano.brd]
2023-03-03 Create Jetson Nano.pdf
    KATOONAMI
